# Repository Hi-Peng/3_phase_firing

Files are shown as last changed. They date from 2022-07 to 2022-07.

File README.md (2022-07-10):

# Pemicu Optik 3 Fasa
Ini merupakan repository untuk proyek pemicu 3 fasa.

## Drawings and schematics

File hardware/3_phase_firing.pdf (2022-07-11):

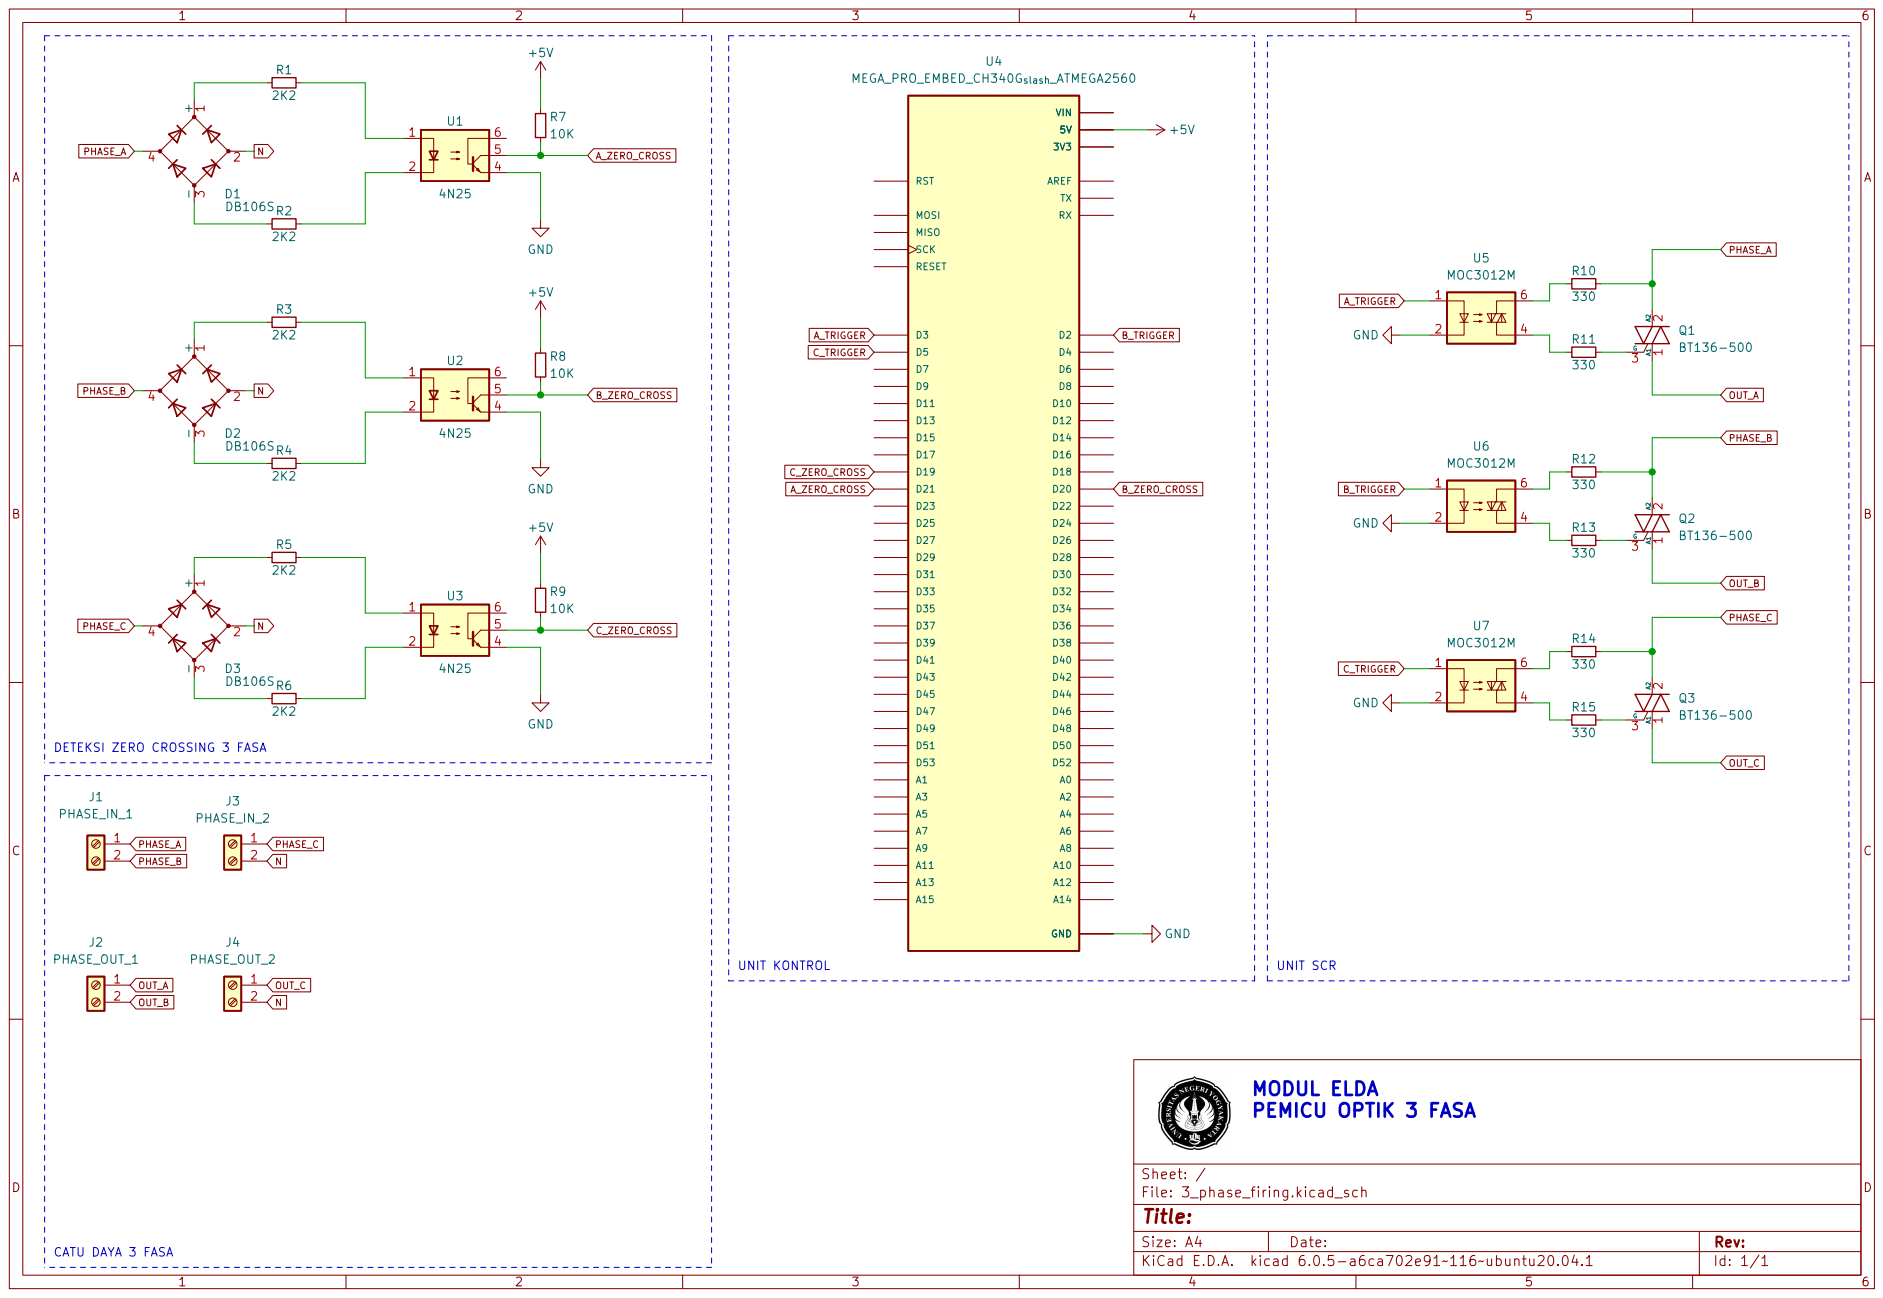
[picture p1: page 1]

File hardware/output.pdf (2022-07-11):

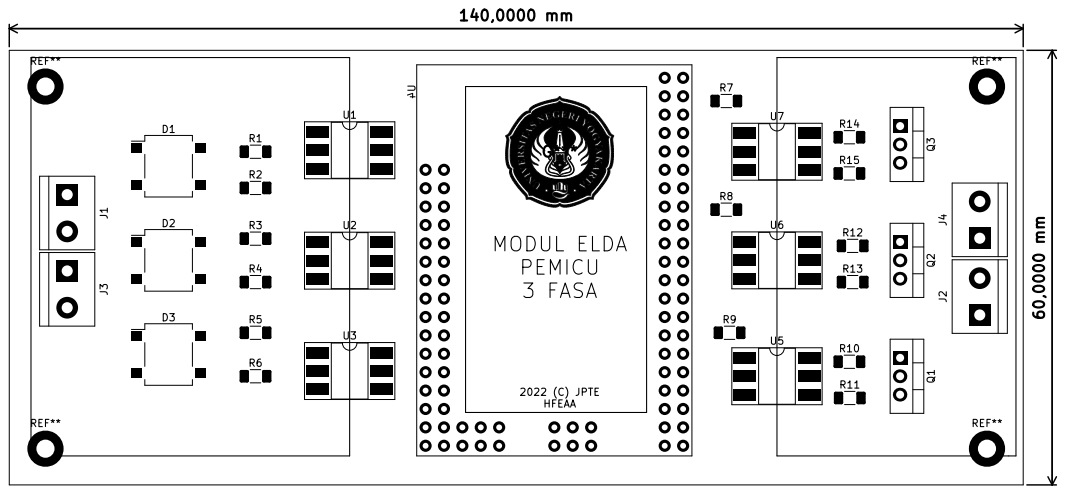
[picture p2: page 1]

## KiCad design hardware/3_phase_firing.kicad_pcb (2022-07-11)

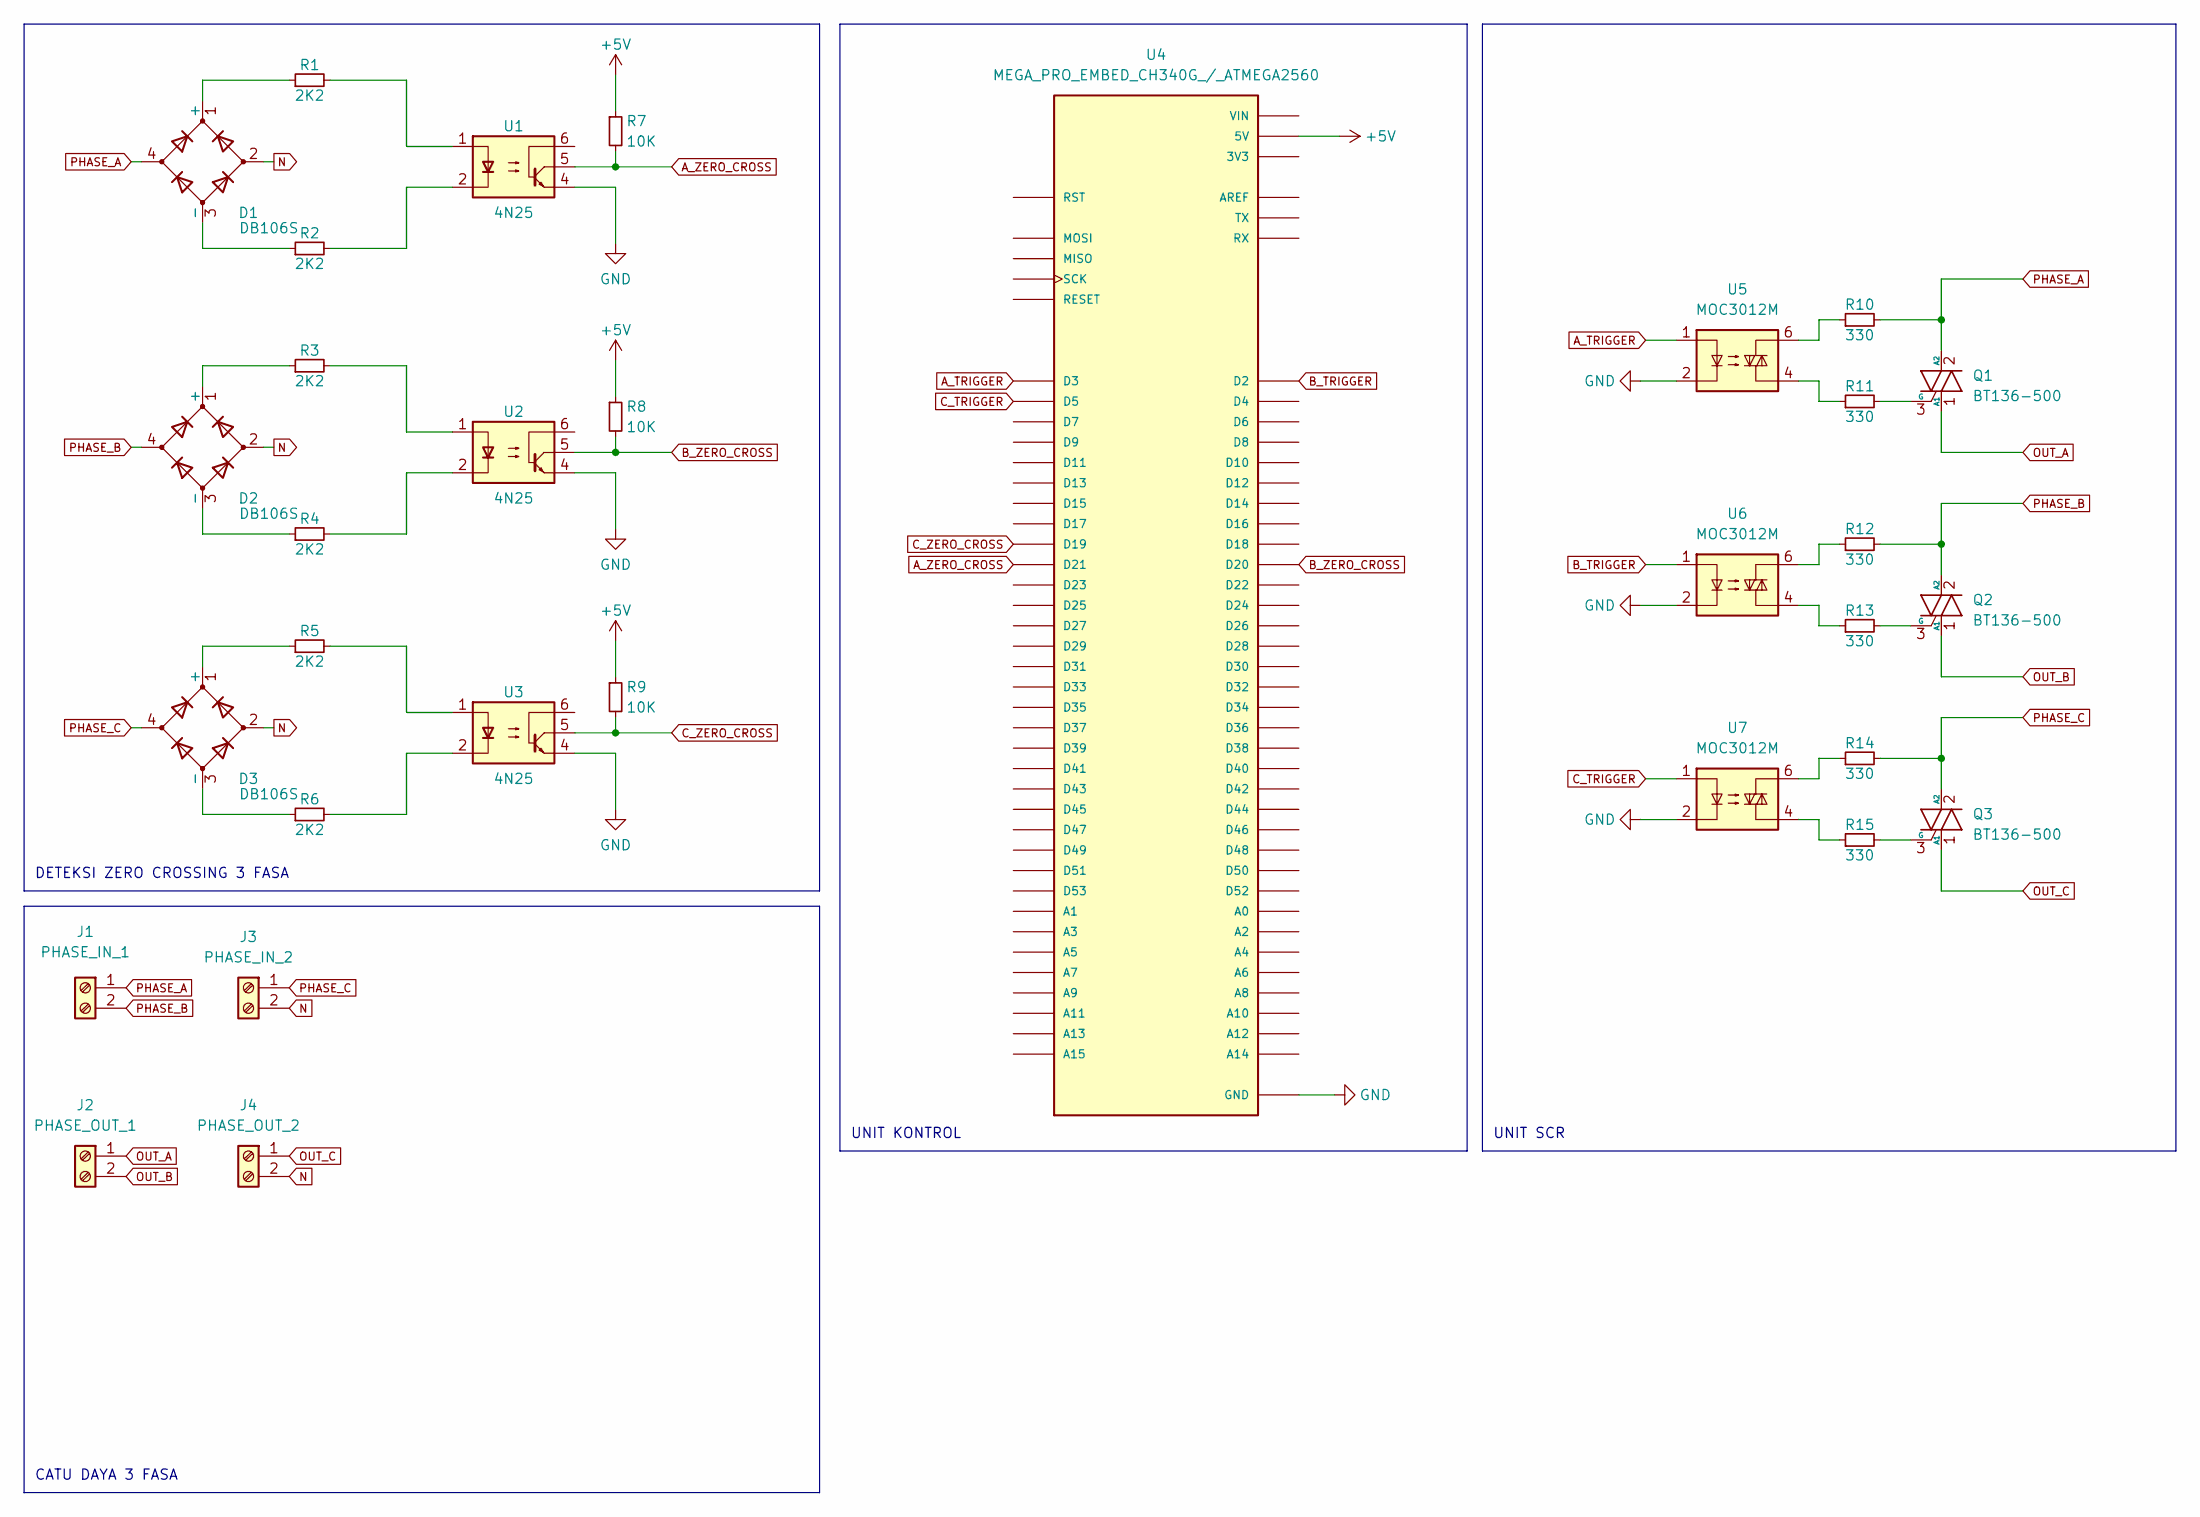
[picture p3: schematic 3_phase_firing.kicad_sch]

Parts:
D1, D2, D3: DB106S; Diode_Bridge_OnSemi_SDIP-4L
J1: PHASE_IN_1; TerminalBlock_bornier-2_P5.08mm
J2: PHASE_OUT_1; TerminalBlock_bornier-2_P5.08mm
J3: PHASE_IN_2; TerminalBlock_bornier-2_P5.08mm
J4: PHASE_OUT_2; TerminalBlock_bornier-2_P5.08mm
Q1, Q2, Q3: BT136-500; TO-220-3_Vertical
R1, R2, R3, R4, R5, R6: 2K2; R_1206_3216Metric_Pad1.30x1.75mm_HandSolder
R7, R8, R9: 10K; R_1206_3216Metric_Pad1.30x1.75mm_HandSolder
R10, R11, R12, R13, R14, R15: 330; R_1206_3216Metric_Pad1.30x1.75mm_HandSolder
U1, U2, U3: 4N25; DIP-6_W8.89mm_SMDSocket_LongPads
U4: MEGA_PRO_EMBED_CH340G_/_ATMEGA2560; MODULE_MEGA_PRO_EMBED_CH340G___ATMEGA2560; PARTREV 12/May/2017
U5, U6, U7: MOC3012M; DIP-6_W8.89mm_SMDSocket_LongPads

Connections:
+5V: R7.1, R8.1, R9.1, U4.5V_1 (5V), U4.5V_2 (5V), U4.5V_3 (5V)
A_TRIGGER: U4.D3, U5.1
A_ZERO_CROSS: R7.2, U1.5, U4.D21
B_TRIGGER: U4.D2, U6.1
B_ZERO_CROSS: R8.2, U2.5, U4.D20
C_TRIGGER: U4.D5, U7.1
C_ZERO_CROSS: R9.2, U3.5, U4.D19
GND: U1.4, U2.4, U3.4, U4.GND_1 (GND), U4.GND_2 (GND), U4.GND_3 (GND), U5.2, U6.2, U7.2
N: D1.2, D2.2, D3.2, J3.2, J4.2
unnamed: D1.1 (+), R1.1
unnamed: D1.3 (-), R2.1
unnamed: D2.1 (+), R3.1
unnamed: D2.3 (-), R4.1
unnamed: D3.1 (+), R5.1
unnamed: D3.3 (-), R6.1
unnamed: Q1.3 (G), R11.2
unnamed: Q2.3 (G), R13.2
unnamed: Q3.3 (G), R15.2
unnamed: R1.2, U1.1
unnamed: R2.2, U1.2
unnamed: R3.2, U2.1
unnamed: R4.2, U2.2
unnamed: R5.2, U3.1
unnamed: R6.2, U3.2
unnamed: R10.1, U5.6
unnamed: R11.1, U5.4
unnamed: R12.1, U6.6
unnamed: R13.1, U6.4
unnamed: R14.1, U7.6
unnamed: R15.1, U7.4
unnamed: U4.3V3_1 (3V3), U4.3V3_2 (3V3)
unnamed: U4.VIN_1 (VIN), U4.VIN_2 (VIN)
OUT_A: J2.1, Q1.1 (A1)
OUT_B: J2.2, Q2.1 (A1)
OUT_C: J4.1, Q3.1 (A1)
PHASE_A: D1.4, J1.1, Q1.2 (A2), R10.2
PHASE_B: D2.4, J1.2, Q2.2 (A2), R12.2
PHASE_C: D3.4, J3.1, Q3.2 (A2), R14.2

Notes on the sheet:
UNIT SCR
UNIT KONTROL
DETEKSI ZERO CROSSING 3 FASA
CATU DAYA 3 FASA

Board: 2 copper layers, 32 parts (1 on the bottom side), 38 nets, no tracks yet.

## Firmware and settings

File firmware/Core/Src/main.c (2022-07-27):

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
/* Includes ------------------------------------------------------------------*/
#include "main.h"

TIM_HandleTypeDef htim1;

/* USER CODE BEGIN PV */
#define SCR_PULSE_WIDTH 1000
int first_wave_flag = 0;
uint16_t pulse_width_ch2 = 0;
uint16_t pulse_width_ch3 = 0;
/* USER CODE END PV */

void SystemClock_Config(void);
static void MX_GPIO_Init(void);
static void MX_TIM1_Init(void);
/* USER CODE BEGIN PFP */
void set_alpha(int alpha);
/* USER CODE END PFP */

/**
  * @brief  The application entry point.
  * @retval int
  */
int main(void)
{
  /* MCU Configuration--------------------------------------------------------*/

  /* Reset of all peripherals, Initializes the Flash interface and the Systick. */
  HAL_Init();

  /* Configure the system clock */
  SystemClock_Config();

  /* Initialize all configured peripherals */
  MX_GPIO_Init();
  MX_TIM1_Init();
  /* USER CODE BEGIN 2 */
  HAL_TIM_Base_Start_IT(&htim1);
  HAL_TIM_OC_Start_IT(&htim1, TIM_CHANNEL_2);
  HAL_TIM_OC_Start_IT(&htim1, TIM_CHANNEL_3);
  /* USER CODE END 2 */

  /* Infinite loop */
  /* USER CODE BEGIN WHILE */
  while (1)
  {
    /* USER CODE END WHILE */

}

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
/* USER CODE BEGIN 4 */
// Sementara belum digunakan
void HAL_TIM_TriggerCallback(TIM_HandleTypeDef * htim){
	// Zero cross wave detect will change flags
	if(first_wave_flag != 1)
		first_wave_flag = 1;
	else
		first_wave_flag = 0;
}

void HAL_TIM_OC_DelayElapsedCallback(TIM_HandleTypeDef *htim){
	if(htim->Channel == HAL_TIM_ACTIVE_CHANNEL_2){
		if (__HAL_TIM_GET_COUNTER(&htim1) >= __HAL_TIM_GET_COMPARE(&htim1, TIM_CHANNEL_2)){
			pulse_width_ch2 = __HAL_TIM_GET_COMPARE(&htim1, TIM_CHANNEL_2) + SCR_PULSE_WIDTH;
			__HAL_TIM_SET_COMPARE(&htim1, TIM_CHANNEL_2, pulse_width_ch2);
		}
	}

	if(htim->Channel == HAL_TIM_ACTIVE_CHANNEL_3){
		if (__HAL_TIM_GET_COUNTER(&htim1) >= __HAL_TIM_GET_COMPARE(&htim1, TIM_CHANNEL_3)){
			pulse_width_ch3 = __HAL_TIM_GET_COMPARE(&htim1, TIM_CHANNEL_3) + SCR_PULSE_WIDTH;
			__HAL_TIM_SET_COMPARE(&htim1, TIM_CHANNEL_3, pulse_width_ch3);
		}
	}
}

void set_alpha(int alpha){
	__HAL_TIM_SET_COMPARE(&htim1, TIM_CHANNEL_2, alpha);
	__HAL_TIM_SET_COMPARE(&htim1, TIM_CHANNEL_3, alpha);
}
/* USER CODE END 4 */
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


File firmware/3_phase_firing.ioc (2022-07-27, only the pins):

Mcu.UserName=STM32F103C6Tx
PA10.Signal=S_TIM1_CH3
PA13.Signal=SYS_JTMS-SWDIO
PA14.Signal=SYS_JTCK-SWCLK
PA8.Signal=S_TIM1_CH1
PA9.Signal=S_TIM1_CH2
PC13-TAMPER-RTC.GPIO_Label=LED_PIN
PC13-TAMPER-RTC.Signal=GPIO_Output
PD0-OSC_IN.Signal=RCC_OSC_IN
PD1-OSC_OUT.Signal=RCC_OSC_OUT

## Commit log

2022-07-10 repo init
    [3_phase_firing.kicad_pcb, 3_phase_firing.kicad_sch]
2022-07-10 completing zero detector circuit
    [3_phase_firing.kicad_sch]
2022-07-11 done with schematic + pcb
    [3_phase_firing.kicad_pcb, 3_phase_firing.kicad_sch]
2022-07-11 pcb done
    [3_phase_firing.kicad_pcb]
2022-07-12 updating gitignore
    [3_phase_firing.kicad_sch]
2022-07-12 reconfiguring timers and clocks
